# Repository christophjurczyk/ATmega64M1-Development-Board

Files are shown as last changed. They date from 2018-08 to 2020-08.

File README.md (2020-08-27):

# ATmega64M1-Development-Board (Arduino-Compatible)
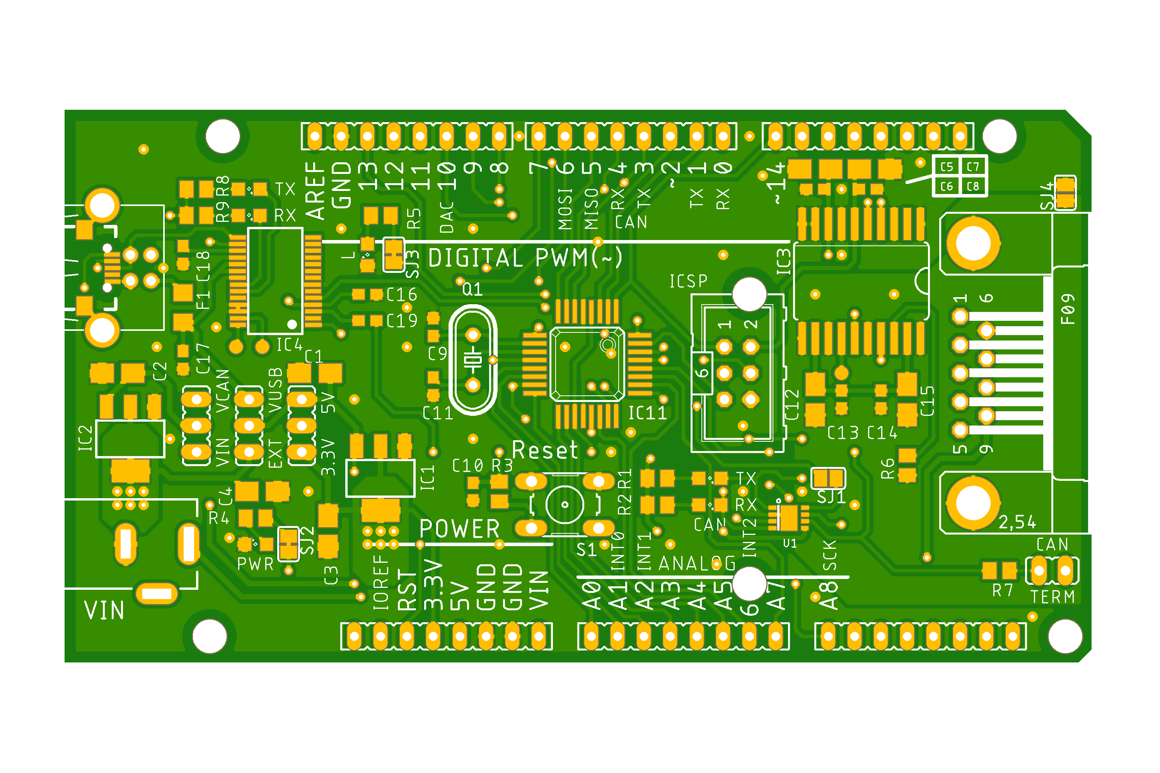
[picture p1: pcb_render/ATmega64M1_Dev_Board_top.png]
pcb


This projects brings an Arduino-compatible development board for the Atmel ATmega64M1 microcontroller. The ATmega64M1 is an 8-bit AVR RISC-based microcontroller and with the CAN capabilities widely used in the automotive industry.

The microcontroller has some additional features to the widely-used Arduino UNO:
- CAN interface
- DAC
- internal temperature sensor

With the help of ATmegaxxM1-C1 Arduino Core of thomasonw (https://github.com/thomasonw/ATmegaxxM1-C1) it is possible to work with the Arduino environment on this board. But you are also able to program the board directly via an ICSP and a dedicated programmer.

## Notes
### CAN Interface
The CAN interface can be handled by two CAN transceivers. You can choose between an isolated (ADM3053) and a non-isolated (MCP2562) CAN transceiver. If you are using the ADM3053, you have to equip the board with R6 and C12 to C15. C5 to C8 are mandatory for both configurations.

### Power Supply
You power the board via three different ways: USB, VIN (DC-Jack or pin header) or CAN interface (3: GND and 9: VCC). You can configure the power supply via the jumper JP2 and JP3 next to the DC-Jack. 
If you are using the CAN interface as power provision, you have to close the solder jumper SJ4 next to the CAN interface. **Caution:** If you are closing this jumper the grounds of the board and CAN interface are no more isolated to each other!

### Logic Level
You can run the controller with 5V or 3.3V. You can configure this via the jumper JP4 next to the DC-Jack.

# Bill of Materials (Thanks to @elasticdotventures)
Per Unit in non-isolated can bus (MCP2562 config)

### Chips:
* 1x ATMEGA64M1 IC11
* 1x FT232RL  IC4
* 1x MCP2562  U1

### Capacitors: 
* 6x smd 1206 / 3216 polar 10uf tantulum    c1,c2,c3,c4,c5,c7
* 6x smd 0805 / 2012 non-polar 100nf    c6,c8,c16,c17,c18,c19
* 2x smd 0805 / 2012 non-polar 22pf   c9,c11

### Oscillators:
* 16mhz Q1

### Voltage Regulator:
* AMS1117 LM1117IMPX-3.3 15Vin 3.3Vout 800ma SOT223	IC1    	
* AMS1117 LM1117IMPX-5.0 15Vin 3.3Vout 800ma SOT223  IC2	   

### 0805 / 2012 Resistors:
* 6x 1k r1,r2,r4,r5, r8,r9
* 1x 10k resistor    R3				
* 1x 120ohm resistor  r7

### 0805 Leds:
* 6x color your choice

### Misc: 
* 1x X1 micro USB
* 1x ISCP connector 3x2 pin header 	SV1
* 1x DC Jack - DCJ0202  J1
* 1x sw1 (reset)
* 6x surface jumpers  sj1,sj2,sj3,sj4,sj5
* 1x smd fuse 1206 f1

### Optional isolated can bus ADM3053
2x smd 1206 / 3216 polar 10uf  C12,c15						
2x smd 0805 / 2012 non-polar 100uf  c13,14   
1x 47k 0805 resistor r6

### Improved CAN terminator (replaces r7 120ohm) - coming soon!
2 x 60ohm  r7a r7b
1 x 4.7nf capacitor

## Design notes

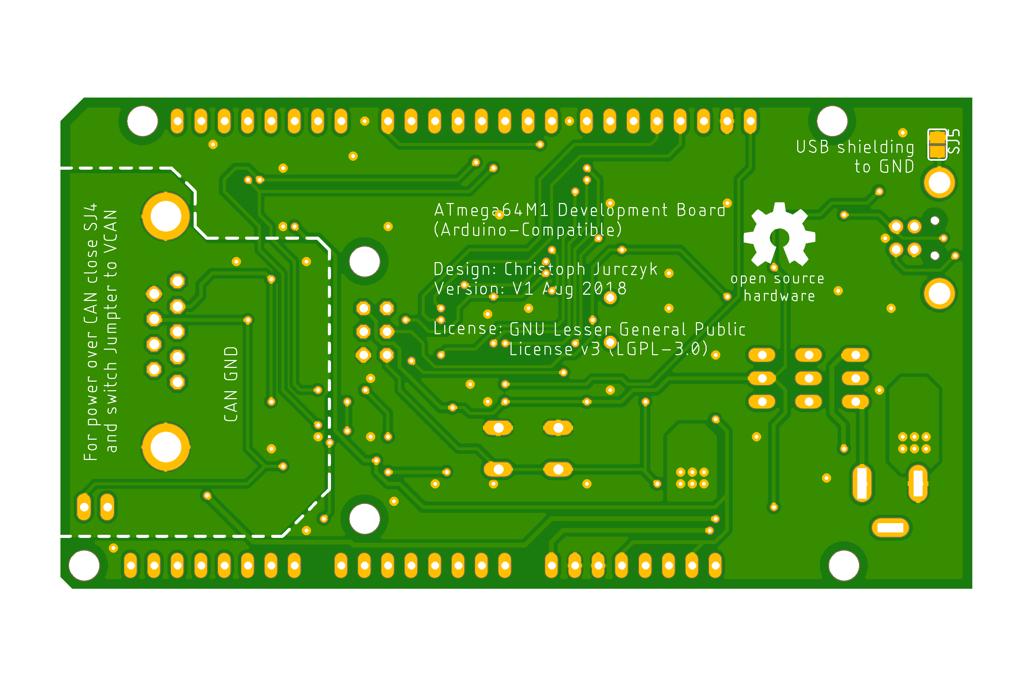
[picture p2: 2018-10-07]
pcb_render/ATmega64M1_Dev_Board_bottom.png

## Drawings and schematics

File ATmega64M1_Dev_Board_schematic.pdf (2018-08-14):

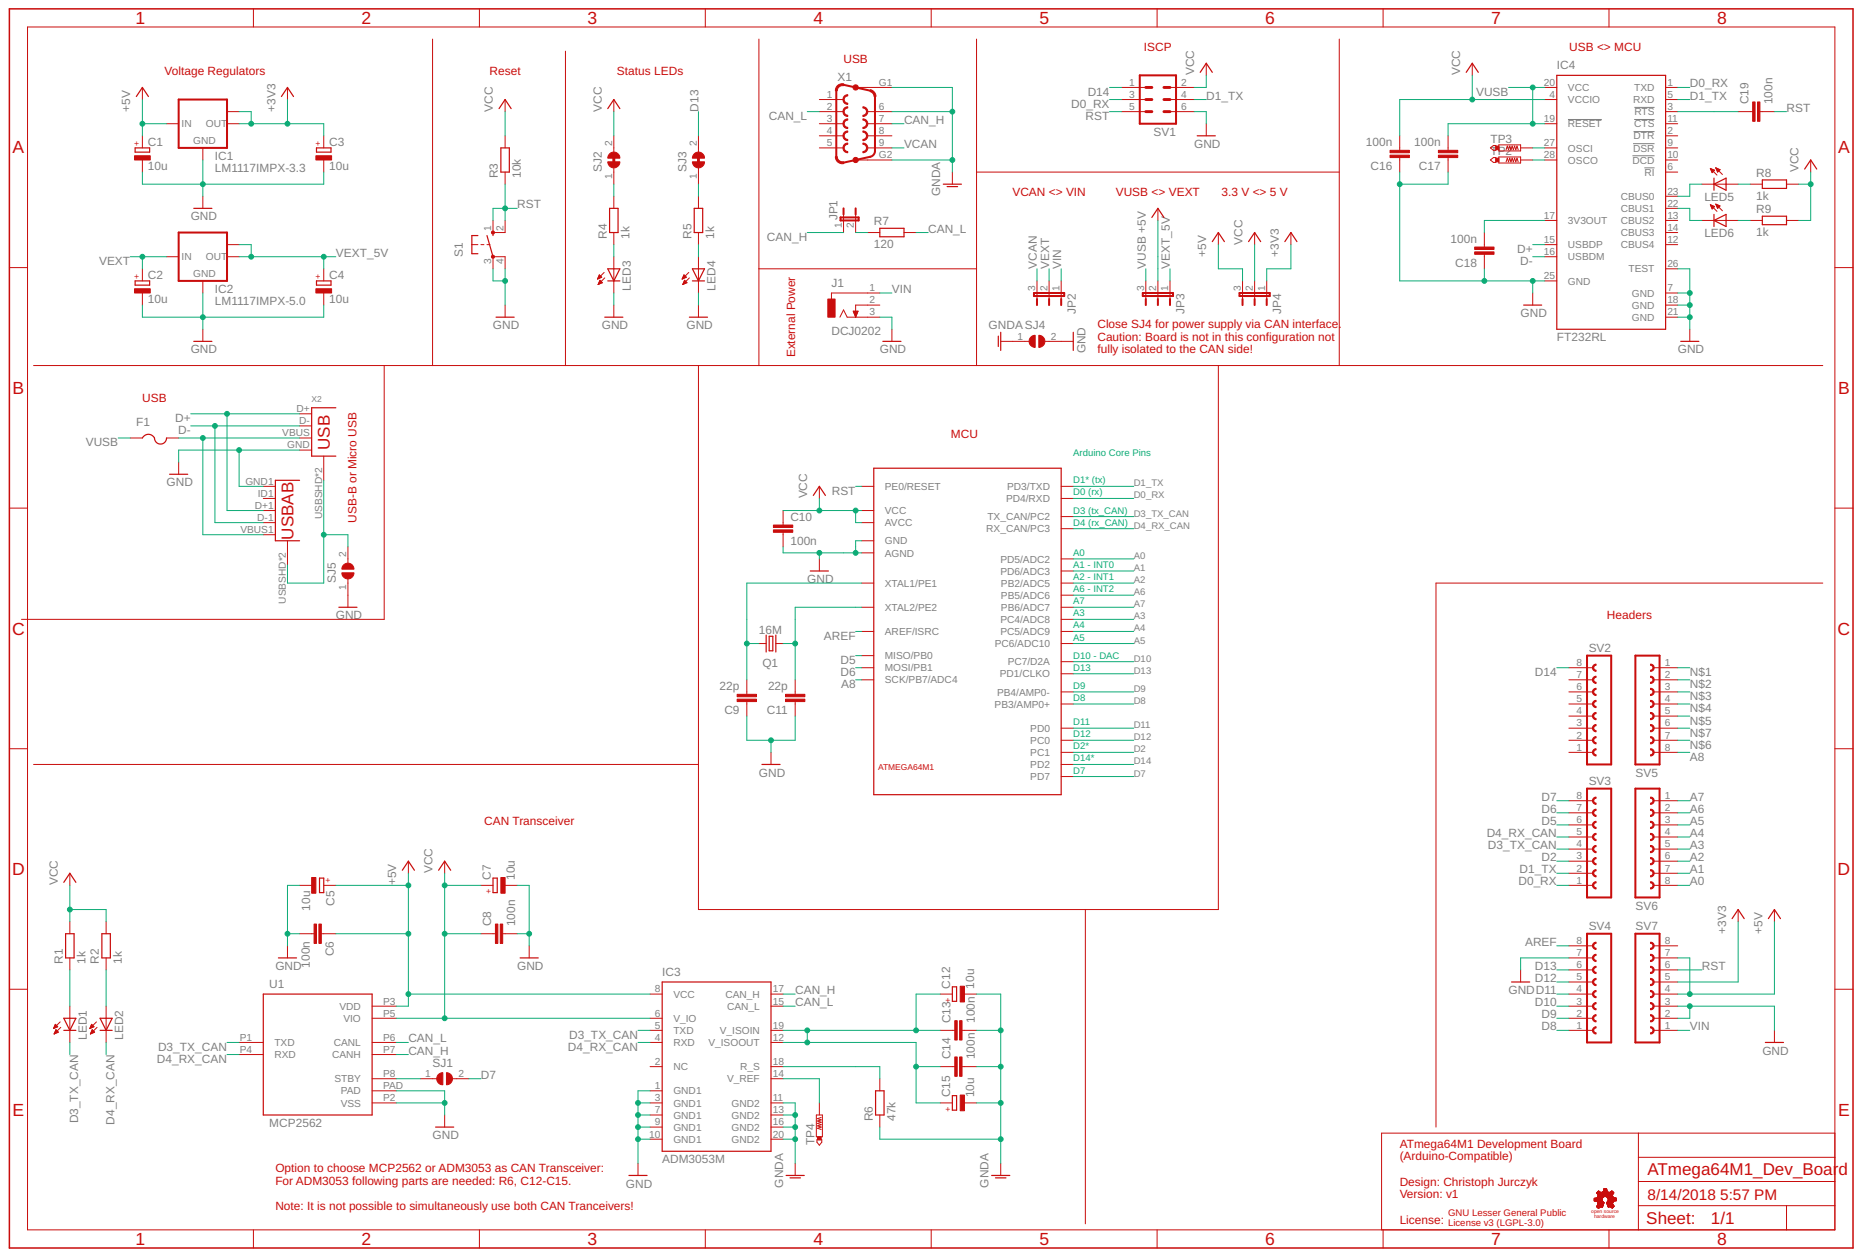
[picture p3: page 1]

GND
fully isolated to the CAN side!

Close SJ4 for power supply via CAN interface. Caution: Board is not in this configuration not

USB-B or Micro USB

ATmega64M1 Development Board (Arduino-Compatible) Design: Christoph Jurczyk Version: v1 GNU Lesser General Public License v3 (LGPL-3.0) open source License: hardware

Option to choose MCP2562 or ADM3053 as CAN Transceiver: For ADM3053 following parts are needed: R6, C12-C15. Note: It is not possible to simultaneously use both CAN Tranceivers!

Sheet: 1/1

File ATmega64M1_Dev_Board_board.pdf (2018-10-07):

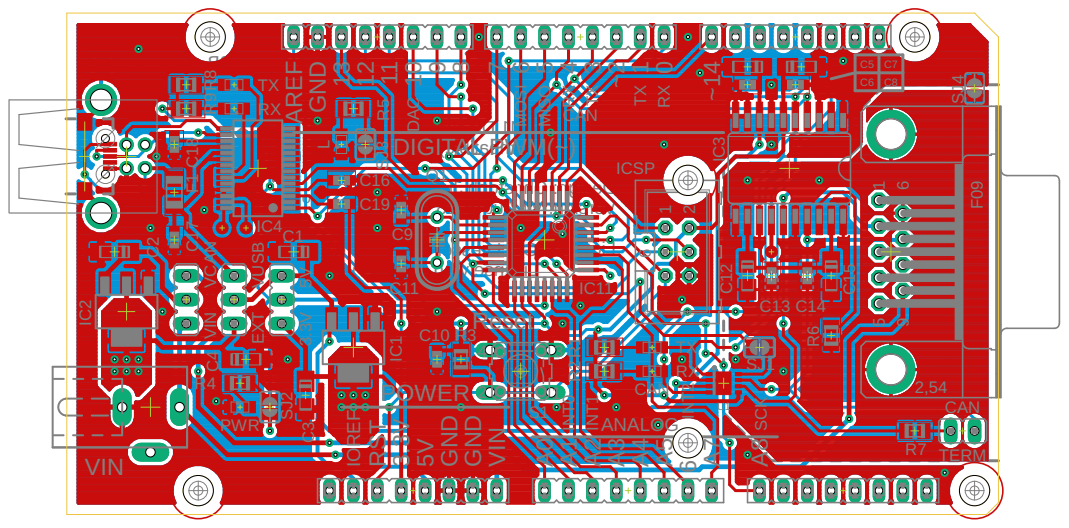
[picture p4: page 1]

and switch Jumpter to VCAN

For power over CAN close SJ4

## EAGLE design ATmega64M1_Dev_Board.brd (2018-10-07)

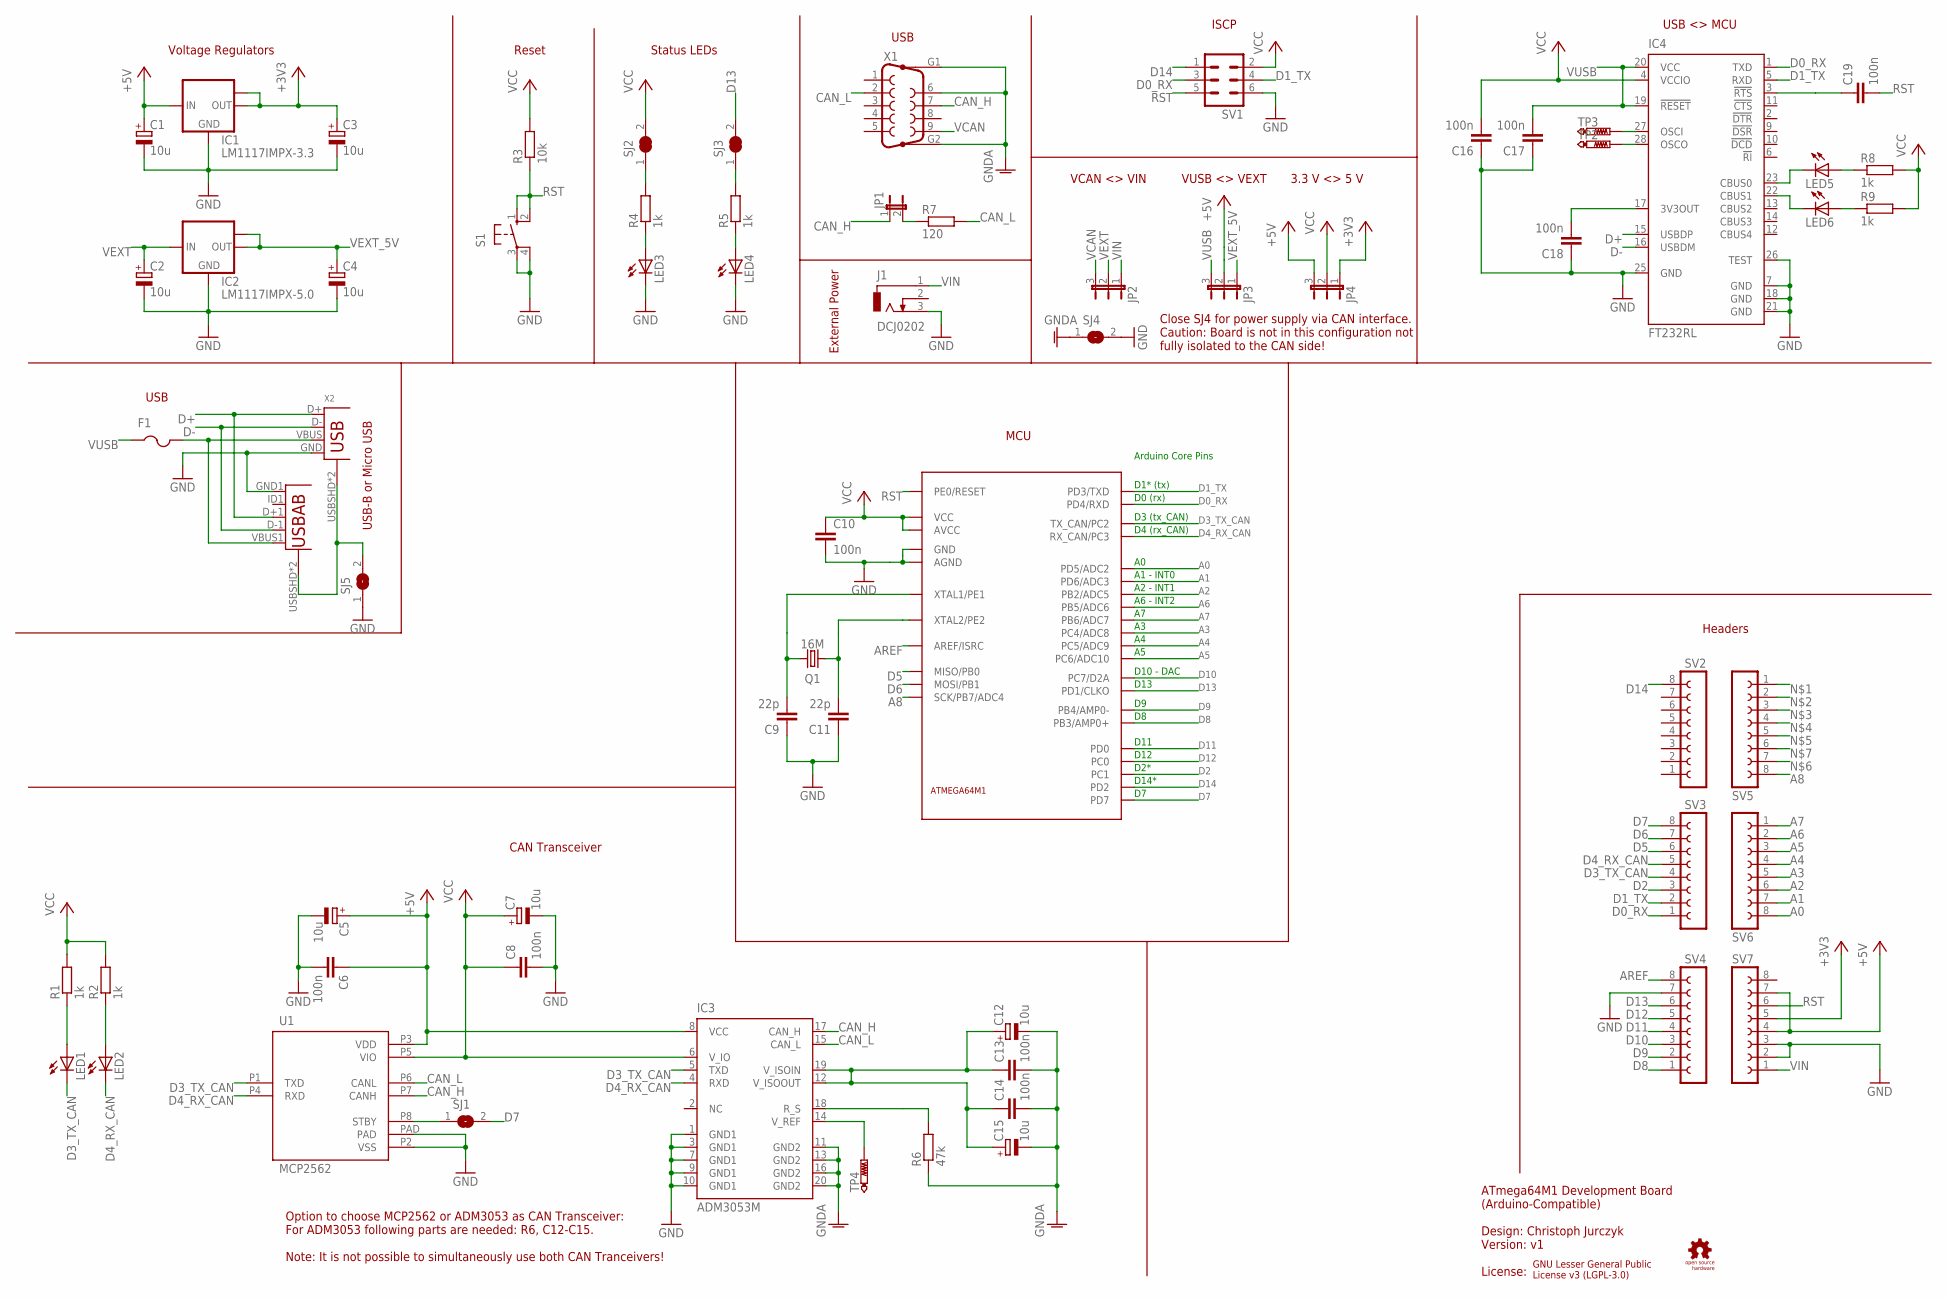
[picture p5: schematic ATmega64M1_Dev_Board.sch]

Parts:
C1, C2, C3, C4, C5, C7, C12, C15: 10u; A/3216-18W
C6, C8, C10, C13, C14, C16, C17, C18, C19: 100n; C0603
C9, C11: 22p; C0603
F1: PTCFUSE-1206; R1206
GOLD_ORB_SM1: OSHWLOGOLOGO8MM; OSHW_8MM
IC1: LM1117IMPX-3.3; SOT223
IC2: LM1117IMPX-5.0; SOT223
IC3: ADM3053M; SO20W
IC4: FT232RL; SSOP28
IC11: ATMEGA64M1TQFP32; QFP-32
J1: DCJ0202
JP1: JP1E; JP1
JP2, JP3, JP4: JP2E; JP2
LED1, LED2, LED3, LED4, LED5, LED6: LEDSML0805; SML0805
Q1: 16M; HC49/S
R1, R2, R4, R5, R8, R9: 1k; M0805
R3: 10k; M0805
R6: 47k; M0805
R7: 120; M0805
S1: 10-XX; B3F-10XX
SJ1, SJ4, SJ5: SJ
SJ2, SJ3: SJ_NC
SV1: ML6
SV2, SV3, SV4, SV5, SV6, SV7: FE08-1; FE08
TP2, TP3, TP4: PTR1B1,27; B1,27
U1: MCP2562; DFN3X3
U2: USB; USB-MICRO-SMD_WITHOUT_PASTE
X1: F09HP
X2: USB-B-H

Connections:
+3V3: C3.+, IC1.2 (OUT), IC1.TAB (OUT1), JP4.1, SV7.5
+5V: C1.+, C5.+, C6.1, IC1.3 (IN), IC3.8 (VCC), JP3.2, JP4.3, SV7.4, SV7.7, U1.P3 (VDD)
A0: IC11.13 (PD5/ADC2), SV6.8
A1: IC11.14 (PD6/ADC3), SV6.7
A2: IC11.16 (PB2/ADC5), SV6.6
A3: IC11.17 (PC4/ADC8), SV6.5
A4: IC11.18 (PC5/ADC9), SV6.4
A5: IC11.22 (PC6/ADC10), SV6.3
A6: IC11.26 (PB5/ADC6), SV6.2
A7: IC11.27 (PB6/ADC7), SV6.1
A8: IC11.28 (SCK/PB7/ADC4), SV5.8
AREF: IC11.21 (AREF/ISRC), SV4.8
CAN_H: IC3.17 (CAN_H), JP1.1, U1.P7 (CANH), X1.7
CAN_L: IC3.15 (CAN_L), R7.2, U1.P6 (CANL), X1.2
D0_RX: IC4.1 (TXD), IC11.12 (PD4/RXD), SV1.3, SV3.1
D1_TX: IC4.5 (RXD), IC11.2 (PD3/TXD), SV1.4, SV3.2
D2: IC11.3 (PC1), SV3.3
D3_TX_CAN: IC3.5 (TXD), IC11.6 (TX_CAN/PC2), LED1.C, SV3.4, U1.P1 (TXD)
D4_RX_CAN: IC3.4 (RXD), IC11.7 (RX_CAN/PC3), LED2.C, SV3.5, U1.P4 (RXD)
D5: IC11.8 (MISO/PB0), SV3.6
D6: IC11.9 (MOSI/PB1), SV3.7
D7: IC11.15 (PD7), SJ1.2, SV3.8
D8: IC11.23 (PB3/AMP0+), SV4.1
D9: IC11.24 (PB4/AMP0-), SV4.2
D10: IC11.25 (PC7/D2A), SV4.3
D11: IC11.29 (PD0), SV4.4
D12: IC11.30 (PC0), SV4.5
D13: IC11.32 (PD1/CLKO), SJ3.2, SV4.6
D14: IC11.1 (PD2), SV1.1, SV2.8
D+: IC4.15 (USBDP), U2.D+1 (D+), X2.D+
D-: IC4.16 (USBDM), U2.D-1 (D-), X2.D-
GND: C1.-, C2.-, C3.-, C4.-, C5.-, C6.2, C7.-, C8.2, C9.1, C10.2, C11.1, C16.1, C17.1, C18.1, IC1.1 (GND), IC2.1 (GND), IC3.1 (GND1), IC3.3 (GND1), IC3.7 (GND1), IC3.9 (GND1), IC3.10 (GND1), IC4.7 (GND), IC4.18 (GND), IC4.21 (GND), IC4.25 (GND), IC4.26 (TEST), IC11.5 (GND), IC11.20 (AGND), J1.3, LED3.C, LED4.C, S1.3, S1.4 (P1), SJ4.2, SJ5.1, SV1.6, SV4.7, SV7.2, SV7.3, U1.P2 (VSS), U1.PAD, U2.GND1 (GND), X2.GND
GNDA: C12.-, C13.2, C14.2, C15.-, IC3.11 (GND2), IC3.13 (GND2), IC3.16 (GND2), IC3.20 (GND2), R6.1, SJ4.1, X1.6, X1.G1, X1.G2
unnamed: F1.2, U2.VBUS1 (VBUS), X2.VBUS
unnamed: SJ1.1, U1.P8 (STBY)
unnamed: C12.+, C13.1, C14.1, C15.+, IC3.12 (V_ISOOUT), IC3.19 (V_ISOIN)
unnamed: IC4.27 (OSCI), TP3.TP
unnamed: C18.2, IC4.17 (3V3OUT)
unnamed: IC3.18 (R_S), R6.2
unnamed: IC4.28 (OSCO), TP2.TP
unnamed: C19.1, IC4.3 (!RTS)
unnamed: IC4.22 (CBUS1), LED6.C
unnamed: IC4.23 (CBUS0), LED5.C
unnamed: LED6.A, R9.1
unnamed: LED5.A, R8.1
unnamed: JP1.2, R7.1
unnamed: LED3.A, R4.1
unnamed: LED4.A, R5.1
unnamed: LED2.A, R2.1
unnamed: LED1.A, R1.1
unnamed: IC3.14 (V_REF), TP4.TP
unnamed: R5.2, SJ3.1
unnamed: R4.2, SJ2.1
unnamed: SJ5.2, U2.USBSHD, U2.USBSHD1 (USBSHD), X2.USBSHD, X2.USBSHD2 (USBSHD)
RST: C19.2, IC11.31 (PE0/RESET), R3.1, S1.1 (S), S1.2 (S1), SV1.5, SV7.6
VCAN: JP2.3, X1.9
VCC: C7.+, C8.1, C10.1, C16.2, IC3.6 (V_IO), IC4.4 (VCCIO), IC11.4 (VCC), IC11.19 (AVCC), JP4.2, R1.2, R2.2, R3.2, R8.2, R9.2, SJ2.2, SV1.2, U1.P5 (VIO)
VEXT: C2.+, IC2.3 (IN), JP2.2
VEXT_5V: C4.+, IC2.2 (OUT), IC2.TAB (OUT1), JP3.1
VIN: J1.1, JP2.1, SV7.1
VUSB: C17.2, F1.1, IC4.19 (!RESET), IC4.20 (VCC), JP3.3
XTAL1: C9.2, IC11.10 (XTAL1/PE1), Q1.2
XTAL2: C11.2, IC11.11 (XTAL2/PE2), Q1.1

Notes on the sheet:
D1* (tx)
D0 (rx)
D3 (tx_CAN)
D4 (rx_CAN)
A1 - INT0
A2 - INT1
A6 - INT2
D10 - DAC
D13
D11
D12
D2*
D14*
Arduino Core Pins
ISCP
VUSB <> VEXT
3.3 V <> 5 V
Option to choose MCP2562 or ADM3053 as CAN Transceiver: For ADM3053 following parts are needed: R6, C12-C15. Note: It is not possible to simultaneously use both CAN Tranceivers!
USB
External Power
Status LEDs
Reset
Voltage Regulators
USB <> MCU
MCU
Headers
CAN Transceiver
ATmega64M1 Development Board (Arduino-Compatible) Design: Christoph Jurczyk Version: v1 License:
VCAN <> VIN
USB-B or Micro USB
GNU Lesser General Public License v3 (LGPL-3.0)
Close SJ4 for power supply via CAN interface. Caution: Board is not in this configuration not fully isolated to the CAN side!

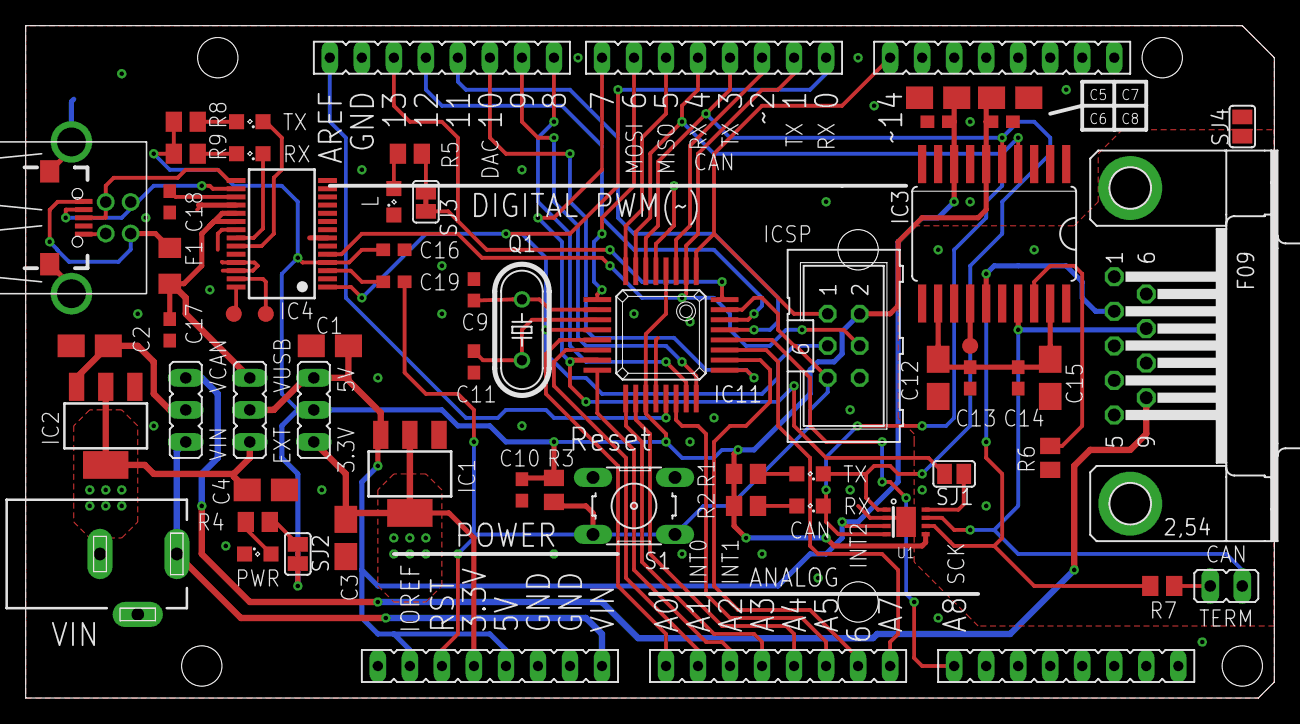
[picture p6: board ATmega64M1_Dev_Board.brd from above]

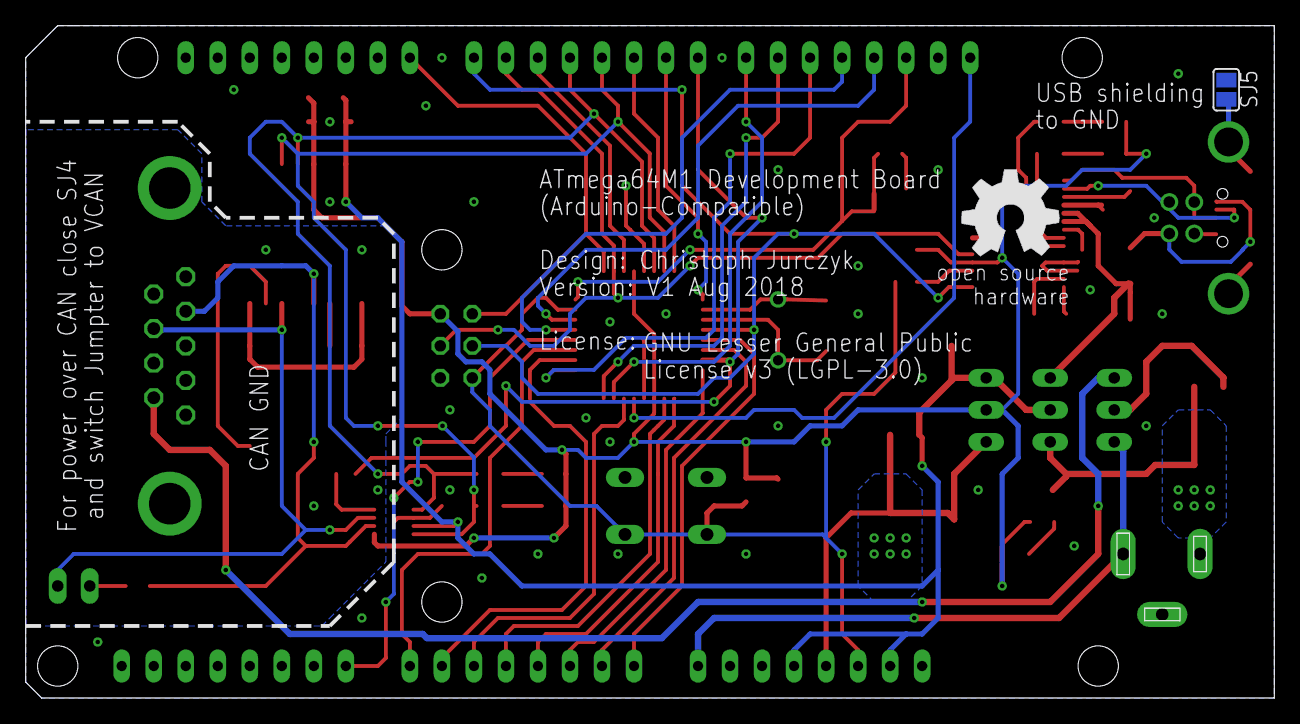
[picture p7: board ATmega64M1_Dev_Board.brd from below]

Board: 2 copper layers, 99.1 x 53.3 mm, 67 parts (2 on the bottom side), 63 nets.

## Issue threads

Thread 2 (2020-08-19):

Bill of materials?

elasticdotventures, 2020-08-19:
Hi @christophjurczyk

Very interesting project. Did I miss an included bill of materials (purchasing list) or way to order & assemble one of these?
I'd very much like to put together a few and do some testing.

I'm developing "GrowPotBot" an ESP32 Can AI indoor garden appliance that will use CAN connected Arduino (or possibly STM32F04) sensors & relays.   The goal is to have the various subsystems coordinate using openCAN and I'm hoping to engage the maker community by having a straightforward Arduino interface with a few extra GPIO's and Analog channels for "other things" people might want to connect to the same system.

I'm trying to re-invent as few technologies as necessary and only use well documented non-patent encumbered open systems.

Let me know if you're interested in collaborating, mentoring or available for hire.
Thanks!

christophjurczyk, 2020-08-27:
Hi @elasticdotventures

Happy to hear that you're interested in the board. Sorry for the late replay. As I saw you collected all parts for a BOM. By the way here is my BOM:

Qty | Value | Device | Package | Parts | Vendor | Pcs/Order | Price/Order | Price/PCB
-- | -- | -- | -- | -- | -- | -- | -- | --
1 |   | 10-XX | B3F-10XX | S1 | Aliexpress | 10 | 0.32 € | 0.03 €
1 |   | F09HP | F09HP | X1 | Aliexpress | 5 | 0.91 € | 0.18 €
6 |   | FE08-1 | FE08 | SV2, SV3, SV4,   SV5, SV6, SV7 | Aliexpress | 10 | 1.05 € | 0.63 €
1 |   | JP1E | JP1 | JP1 | Aliexpress | 10 | 0.70 € | 0.07 €
3 |   | JP2E | JP2 | JP2, JP3, JP4 | Aliexpress | 10 | 0.70 € | 0.21 €
6 |   | LEDSML0805 | SML0805 | LED1, LED2, LED3, LED4, LED5, LED6 | Aliexpress | 100 | 0.87 € | 0.05 €
1 |   | ML6 | ML6 | SV1 | Aliexpress | 10 | 0.83 € | 0.08 €
1 |   | PTCFUSE-1206 | R1206 | F1 | Aliexpress | 100 | 2.10 € | 0.02 €
1 |   | USB | USB-MICRO-SMD_WITHOUT_PASTE | U2 | optional | 1 |   | -   €
1 |   | USB-B-H | USB-B-H | X2 | Aliexpress | 10 | 0.91 € | 0.09 €
9 | 100n | C-EUC0603 | C0603 | C6, C8, C10,   C13, C14, C16, C17, C18, C19 | Aliexpress | 100 | 0.97 € | 0.09 €
1 | 10k | R-EU_M0805 | M0805 | R3 | Aliexpress | 100 | 0.69 € | 0.01 €
8 | 10u | CPOL-EUA/3216-18W | A/3216-18W | C1, C2, C3, C4,   C5, C7, C12, C15 | Aliexpress | 10 | 0.69 € | 0.55 €
1 | 120 | R-EU_M0805 | M0805 | R7 | Aliexpress | 100 | 0.69 € | 0.01 €
1 | 16M | CRYSTALHC49S | HC49/S | Q1 | Aliexpress | 10 | 0.65 € | 0.07 €
6 | 1k | R-EU_M0805 | M0805 | R1, R2, R4, R5, R8, R9 | Aliexpress | 100 | 0.69 € | 0.04 €
2 | 22p | C-EUC0603 | C0603 | C9, C11 | Aliexpress | 100 | 0.85 € | 0.02 €
1 | 47k | R-EU_M0805 | M0805 | R6 | Aliexpress | 100 | 0.69 € | 0.01 €
1 | ADM3053M | ADM3053M | SO20W | IC3 | optional | 1 |   | -   €
1 | ATMEGA64M1 | ATMEGA64M1 | QFN-32 | IC11 | Aliexpress | 3 | 15.79 € | 5.26 €
1 | DCJ0202 | DCJ0202 | DCJ0202 | J1 | Aliexpress | 10 | 0.53 € | 0.05 €
1 | FT232RL | FT232RL | SSOP28 | IC4 | Aliexpress | 1 | 1.26 € | 1.26 €
1 | LM1117IMPX-3.3 | LM1117IMPX-3.3 | SOT223 | IC1 | Aliexpress | 10 | 0.24 € | 0.02 €
1 | LM1117IMPX-5.0 | LM1117IMPX-5.0 | SOT223 | IC2 | Aliexpress | 10 | 0.34 € | 0.03 €
1 | MCP2562 | MCP2562 | DFN3X3 | U1 | distrelec | 1 | 1.05 € | 1.05 €
1 |   | PCB |   |   | JLCPCB | 10 | 11.21 € | 1.12 €
  |   |   |   |   |   |   | Price/PCB: | 10.96   €

Best Regards,
Christoph

Closed 2020-09-05.

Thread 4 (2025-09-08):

Flashing ATMega

Eliot-Abramo, 2025-09-08:
Hi,

Just a quick question regarding how to flash this board. If I add the Arduino extension from "[ATmegaxxM1-C1 (https://github.com/thomasonw/ATmegaxxM1-C1)", can I flash the board by USB directly? Or do I still need the ISCP connector with the dedicated programming tool?

Thank you

christophjurczyk, 2025-09-17:
Initially you need to flash it with ISP (e.g. Arduino core). Thereafter you can use the USB for flashing.

Closed 2025-09-19.

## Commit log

2018-08-09 Initial upload.
    [ATmega64M1_Dev_Board.brd, ATmega64M1_Dev_Board.sch]
2018-08-09 Gerber files for JLCPCB.
2018-08-09 Minor fixes.
    [ATmega64M1_Dev_Board.brd]
2018-08-10 Deleted old gerber files.
2018-08-14 Fixed ICSP pin allocation.
    [ATmega64M1_Dev_Board.brd, ATmega64M1_Dev_Board.sch]
2018-08-27 Fixed typo on silkscreen.
    [ATmega64M1_Dev_Board.brd]
2018-10-07 Added some labels to board.
    [ATmega64M1_Dev_Board.brd]
